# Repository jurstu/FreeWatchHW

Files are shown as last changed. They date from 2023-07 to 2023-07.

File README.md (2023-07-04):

Free Watch Hardware
===================

This repository contains hardware created for Free Watch project based on Waveshare's RP2040 Microcontroller Development Board which has following features:
- [X] rpi2040 microcontroller
- [X] 32.5mm 240x240 round **touch** LCD screen 
- [X] Lithium battery charger
- [X] QMI8658 6-axis IMU
- [X] type-C connector for charging and programming

<a href="https://www.waveshare.com/RP2040-Touch-LCD-1.28.htm">
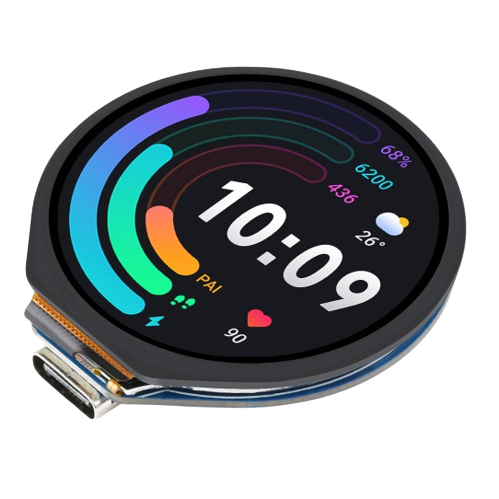
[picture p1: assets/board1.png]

</a>
<a href="https://www.waveshare.com/RP2040-Touch-LCD-1.28.htm">
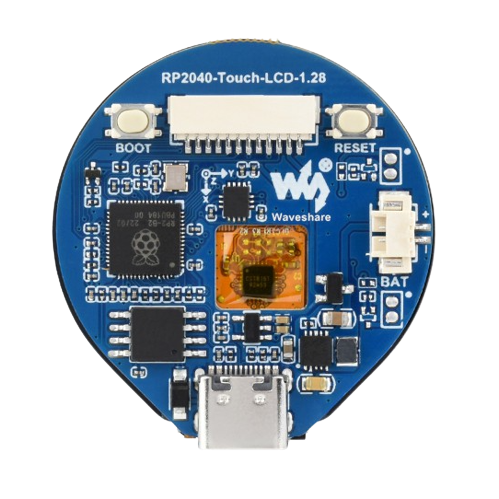
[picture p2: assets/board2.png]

</a>

For a demanding user it lacks a few features, such as:
- [ ] pulsoximeter
- [ ] GPS module
- [ ] side buttons
- [ ] SD card 
- [ ] RTC powered when rpi is off 
- [ ] magnetometer/compass

which is a list of features a second board aims to implement.

Since this is a open-source project it will be created in Ki-Cad.

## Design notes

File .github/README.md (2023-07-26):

Free Watch Hardware
===================

This repository contains hardware created for Free Watch project based on Waveshare's RP2040 Microcontroller Development Board which has following features:
- [X] rpi2040 microcontroller
- [X] 32.5mm 240x240 round **touch** LCD screen 
- [X] Lithium battery charger
- [X] QMI8658 6-axis IMU
- [X] type-C connector for charging and programming

<a href="https://www.waveshare.com/RP2040-Touch-LCD-1.28.htm">

</a>
<a href="https://www.waveshare.com/RP2040-Touch-LCD-1.28.htm">

</a>

<a href="https://www.waveshare.com/RP2040-Touch-LCD-1.28.htm">product page</a>

<a href="https://www.waveshare.com/wiki/RP2040-Touch-LCD-1.28">wiki</a>

<a href="https://www.waveshare.com/w/upload/3/3c/RP2040-Touch-LCD-1.28.pdf">schematic</a>

For a demanding user it lacks a few features, such as:
- [ ] pulsoximeter
- [ ] GPS module
- [ ] side buttons
- [ ] SD card 
- [ ] RTC for powered when rpi is off 
- [ ] magnetometer/compass
- [ ] bluetooth/wifi module (?)

which is a list of features a second board aims to implement.

Since this is a open-source project it will be created in Ki-Cad. 

Reasoning and elements are presented in [PARTS.md](PARTS.md)

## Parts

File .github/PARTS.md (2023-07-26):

Selected parts
==============

problems:
--------
- selected rpi2040 board only shares 6 free pins, which suggests to use I<sup>2</sup>C protocol for as many features as possible (2 additionall are available - 4 and 5, however they aren't on designated header)
- there is no configuration, where we can use SPI0 on second board because of the pins that were selected to be free, SPI1 is used for display
- second board needs 3.3V power, and designated header doesn't provide actual 3.3V regulated power line

Free pins
=========

| pin num | spi option | I<sup>2</sup>C option |  UART option  |  selected purpose
|---|--- | --- |  --- | ---
|  16 |SPI0 RX | **I<sup>2</sup>C0 SDA** |  UART0 TX | **I<sup>2</sup>C0 SDA** 
|  17 |SPI0 CSn | **I<sup>2</sup>C0 SCL** |  UART0 RX | **I<sup>2</sup>C0 SCL**
|  18 |SPI0 SCK | <strike>I<sup>2</sup>C1 SDA </strike> |  UART0 CTS | 
|  26 |<strike>SPI1 SCK</strike> | <strike>I<sup>2</sup>C1 SDA </strike> |  UART1 CTS | 
|  27 |<strike>SPI1 TX </strike> | <strike>I<sup>2</sup>C1 SCL </strike> |  UART1 RTS | 
|  28 |<strike>SPI1 RX </strike> | I<sup>2</sup>C0 SDA |  UART0 TX | 
| 4 |SPI0 RX | I<sup>2</sup>C0 SDA |  UART1 TX | 
| 5 |SPI0 CSn | I<sup>2</sup>C0 SCL |  **UART1 RX** | **UART1 RX** for GPS

I<sup>2</sup>C1 is used onboard for IMU

SPI1 is used for the display, SPI0 has no available TX pin on free pins from the watch module

This probably means, that SD card has to be bitbanged to selected (in near future) pins (**bad idea**), or we need to use PIO in order to exchange data throug SPI **with adequate throughput**

I<sup>2</sup>C devices
======================

| I<sup>2</sup>C device | model | address
| --- | --- | ---
| pulseoximeter | MAX30102 | 0xAE
| RTC | DS3231 | 0x68
| GPIO expander | MCP23009 | 0x20 - 0x27
| Gesture/light sensor  | APDS-9960 | 0x39
| magnetometer/compass  | idk yet | idk yet

This leaves following features to be handled:    
- GPS module (1 pin for serial data)
- side buttons (0 pins since we have GPIO expander)
- SD card (3 pins for SPI and 1 pin from expander)
- bluetooth/wifi module (?)

It would also be nice to be able to turn the GPS module on/off from code using a mosfet or something (1 pin of expander)

GPIO expander pins
==================

| expander pin num | in/out | purpose
| ---| ---| ---
| 0 | in |  button0
| 1 | in |  button1 
| 2 | in |  button2 
| 3 | | 
| 4 | | 
| 5 | | 
| 6 | out | SPI CS for SD 
| 7 | out | GPS power control

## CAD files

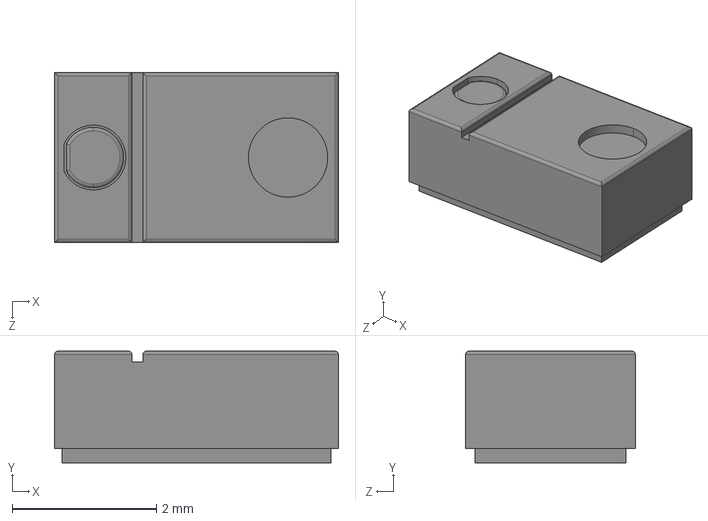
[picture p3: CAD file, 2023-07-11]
secondPCB/FreeWatch/APDS-9960/APDS-9960.step
3.94 x 1.55 x 2.36 mm

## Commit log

2023-07-05 gesture sensor
2023-07-06 first kicad steps
    [FreeWatch.kicad_sch, MAX30102EFD_.step]
2023-07-11 moving on
    [APDS-9960.step, FreeWatch.kicad_sch, MAX30102EFD_.step]
